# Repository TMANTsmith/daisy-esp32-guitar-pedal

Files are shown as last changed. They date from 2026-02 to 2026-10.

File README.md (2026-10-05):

# Daisy Esp32 Pedal

This is a guitar pedal with the goal of combining the audio processing power of the Daisy Seed with the wifi capabilities of the Esp32C series (currently only testing the C6). This way you can fully control the guitar pedal with your phone connected by a website hosted by the esp32 and for low-latantcy tasks physical buttons will be on the board. This will allow for greator flexability through the user being able to add or remove buttons by making changes to the website allowing them to have any configuration they want.

## What is used

### Hardware

The mini-pcb which includes TRS jacks for audio processing does not currently have the esp32 but processing audio with just the daisy seed is working

The full-pcb inclued a esp32 which is connected to the daisy seed through UART (SPI is also connected but is unused) and includes 2 TS jacks this pcb has been designed tested.

#### mini-pcb

- [x] Finished development
- [x] Passed testing

#### full-pcb

| Front | Back |
| :---: | :---: |
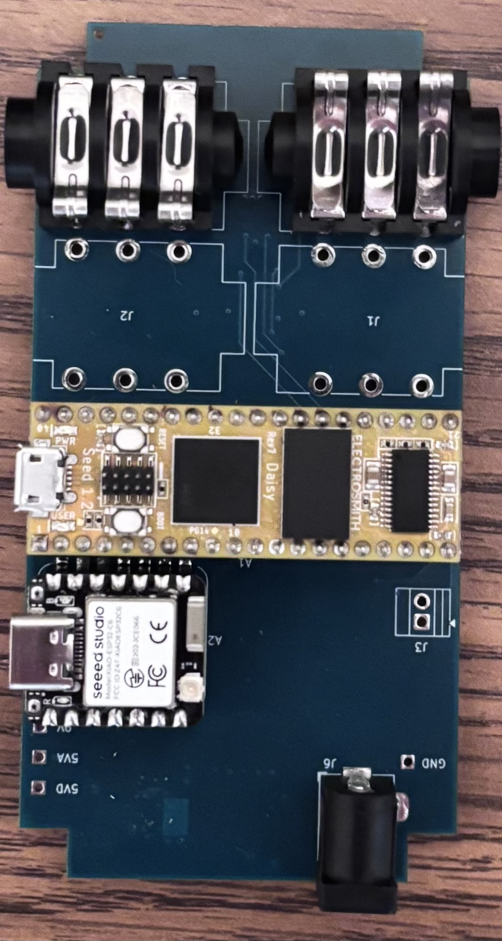
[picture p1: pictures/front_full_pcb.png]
|  |  |

- [x] Finished development
- [x] Passed testing

#### seed-pedal

This will copy the new 3Seed datasheet recommended configuration for instrument level audio and will be the final version

- [ ] Finished development
- [ ] Passed testing

### Software

The project is written in rust and uses embassy as the async exacutor. Specifily the [daisy-embassy](https://github.com/daisy-embassy/daisy-embassy/tree/master) which has some audio stuff, like a DMA buffer, built in.

## Examples

So far there is only one example which is just on main.rs which does a FFT using [microfft](https://gitlab.com/teskje/microfft-rs) but includes things like using the SDRAM on the seed as the heap, interupts and how to share information between them, how to make and use buffer for audio anaysis, and more.

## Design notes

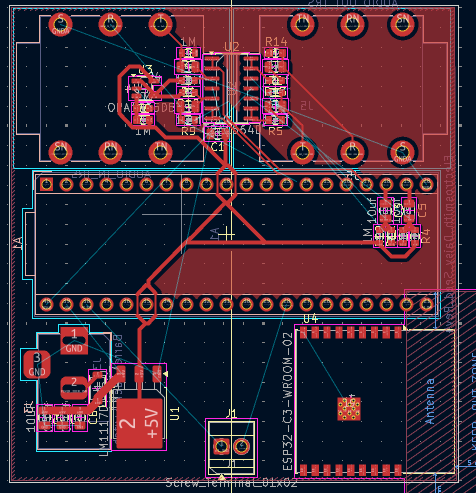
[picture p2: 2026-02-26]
seed-pedal/pcb.png

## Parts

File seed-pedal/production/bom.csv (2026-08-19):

Designator | Footprint | Quantity | Value | LCSC Part #
5VA1, 5VD1, 9V1, GND1 | PinHeader_1x01_P2.54mm_Vertical | 4 | TestPoint
A1 | Electrosmith_Daisy_Seed | 1 | Electrosmith_Daisy_Seed_Rev4 (2 1x20 pin headers required) | C50984
A2 | XIAO-ESP32-C6-DIP | 1 | XIAO-ESP32-C6-DIP (2 1x7 pin headers required) | C5371993
C1, C14, C17, C18, C19, C2 | 0805 | 6 | 0.1uf | C49678
C10, C7 | 0805 | 2 | 2.2nf | C28260
C11 | 0805 | 1 | 0.01uf | C1710
C12 | CP_EIA-3528-21_Kemet-B | 1 | 100uf | C16133
C13, C3, C4, C5, C6, C8, C9 | 0805 | 7 | 10uf | C440198
C15 | CP_EIA-7343-31_Kemet-D | 1 | 220uf | C242173
C16 | 0805 | 1 | 0.33uf | C1740
D1 | D_SMA | 1 | SS14 | C2480
D2, D3 | D_SMA | 2 | SS34 | C8678
D4 | 0805 | 1 | LED | C2297
FB1 | 0603 | 1 | 120Ω@100MHz | C14709
J6 | BarrelJack_Horizontal | 1 | Barrel_Jack_Switch | C16214
L1 | L_Changjiang_FNR8040S | 1 | 18uH | C168130
R1, R11, R8 | 0603 | 3 | 100 | C22775
R10, R14, R7 | 0603 | 3 | 3.3K | C22978
R12, R3, R4, R5, R6, R9 | 0603 | 6 | 2M | C22976
R13, R16, R2 | 0603 | 3 | 10k | C25804
R15 | 0603 | 1 | 1k | C21190
U1 | SOIC-14_3.9x8.7mm_P1.27mm | 1 | OPA1664D | C69414
U2 | TI_SO-PowerPAD-8_ThermalVias | 1 | TPS5430DDA | C9864
U3 | SOT-89-3 | 1 | 78L05G-AB3-R | C71136
U4 | SOT-23-3 | 1 | CJ431 | C3113

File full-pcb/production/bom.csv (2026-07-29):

Designator | Footprint | Quantity | Value | LCSC Part #
C1 | CP_EIA-7343-31_Kemet-D | 1 | 220uf | C242173
C11, C15, C18, C19, C3, C5, C6, C7, C9 | 0805 | 9 | 10uf | C440198
C12, C14, C16, C17 | 0805 | 4 | 0.1uf | C49678
C13, C2 | 0805 | 2 | 2.2nf | C28260
C20 | 0805 | 1 | 0.01uf | C1710
D2 | 0805 | 1 | LED | C2297
D3 | D_SMA | 1 | SS14 | C2480
D5, D6 | D_SMA | 2 | SS34 | C8678
J1, J6 | TerminalBlock_Xinya_XY308-2.54-2P_1x02_P2.54mm_Horizontal | 2 | Screw_Terminal_01x02 | C8465
J3 | BarrelJack_Horizontal | 1 | Barrel_Jack_Switch | C16214
J4, J7 | Jack_6.35mm_Neutrik_NMJ6HCD3_Horizontal | 2 | AUDIO_IN_TRS | C368502
J5, J8 | Jack_6.35mm_Neutrik_NMJ6HCD3_Horizontal | 2 | AUDIO_OUT_TRS | C368502
L1 | L_Changjiang_FNR8040S | 1 | 18uH | C168130
R1, R10, R11, R12, R5, R8 | 0603 | 6 | 2M | C22976
R2, R21, R3 | 0603 | 3 | 100 | C22775
R22, R9 | 0603 | 2 | 10k | C25804
R23, R27 | 0603 | 2 | 1k | C21190
R4, R7 | 0603 | 2 | 3.3K | C22978
R6 | 0603 | 1 | 3.24k | C166817
U1 | SOT-89-3 | 1 | 78L05G-AB3-R | C71136
U2 | SOIC-14_3.9x8.7mm_P1.27mm | 1 | OPA1664D | C69414
U3 | TI_SO-PowerPAD-8_ThermalVias | 1 | TPS5430DDA
U4 | SOT-23-3 | 1 | CJ431 | C3113

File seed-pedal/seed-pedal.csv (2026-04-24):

Reference | Qty | Value | DNP | Exclude from BOM | Exclude from Board | Footprint | Datasheet
A1 | 1 | Electrosmith_Daisy_Seed_Rev4 |  |  |  | Module:Electrosmith_Daisy_Seed | https://static1.squarespace.com/static/58d03fdc1b10e3bf442567b8/t/6227e6236f02fb68d1577146/1646781988478/Daisy_Seed_datasheet_v1.0.3.pdf
C1,C2,C3,C4,C5,C6,C9,C10,C13 | 9 | 10uf |  |  |  | Capacitor_SMD:C_0805_2012Metric | ~
C7,C8,C11,C12 | 4 | 0.1uf |  |  |  | Capacitor_SMD:C_0805_2012Metric | ~
D1 | 1 | 1N5817 |  |  |  | Diode_SMD:D_SOD-123 | http://www.vishay.com/docs/88525/1n5817.pdf
D2 | 1 | LED |  |  |  | LED_SMD:LED_0805_2012Metric | ~
J1 | 1 | Screw_Terminal_01x02 |  |  |  | TerminalBlock:TerminalBlock_Xinya_XY308-2.54-2P_1x02_P2.54mm_Horizontal | ~
J3 | 1 | Barrel_Jack_Switch |  |  |  | Connector_BarrelJack:BarrelJack_Horizontal | ~
J4 | 1 | AUDIO_IN_TRS |  |  |  | Connector_Audio:Jack_6.35mm_Neutrik_NMJ6HCD3_Horizontal
J5 | 1 | AUDIO_OUT_TRS |  |  |  | Connector_Audio:Jack_6.35mm_Neutrik_NMJ6HCD3_Horizontal
R1,R2,R3,R4,R6,R7,R9,R10,R11,R12 | 10 | 1M |  |  |  | Resistor_SMD:R_0603_1608Metric | ~
R5,R15,R17,R20,R22 | 5 | 10k |  |  |  | Resistor_SMD:R_0603_1608Metric | ~
R8,R16,R18,R19 | 4 | 39k |  |  |  | Resistor_SMD:R_0603_1608Metric | ~
R13,R14,R21,R25,R26 | 5 | 100 |  |  |  | Resistor_SMD:R_0603_1608Metric | ~
R23,R24 | 2 | 100k |  |  |  | Resistor_SMD:R_0603_1608Metric | ~
R27 | 1 | 330 |  |  |  | Resistor_SMD:R_0603_1608Metric | ~
U1 | 1 | LM1117DT-5.0 |  |  |  | Package_TO_SOT_SMD:TO-252-3_TabPin2 | http://www.ti.com/lit/ds/symlink/lm1117.pdf
U2 | 1 | OPA1664D |  |  |  | Package_SO:SOIC-14_3.9x8.7mm_P1.27mm | https://www.ti.com/lit/ds/symlink/opa1664.pdf
U3 | 1 | OPA1655DBV |  |  |  | Package_TO_SOT_SMD:SOT-23-5 | https://www.ti.com/lit/ds/symlink/opa1655.pdf

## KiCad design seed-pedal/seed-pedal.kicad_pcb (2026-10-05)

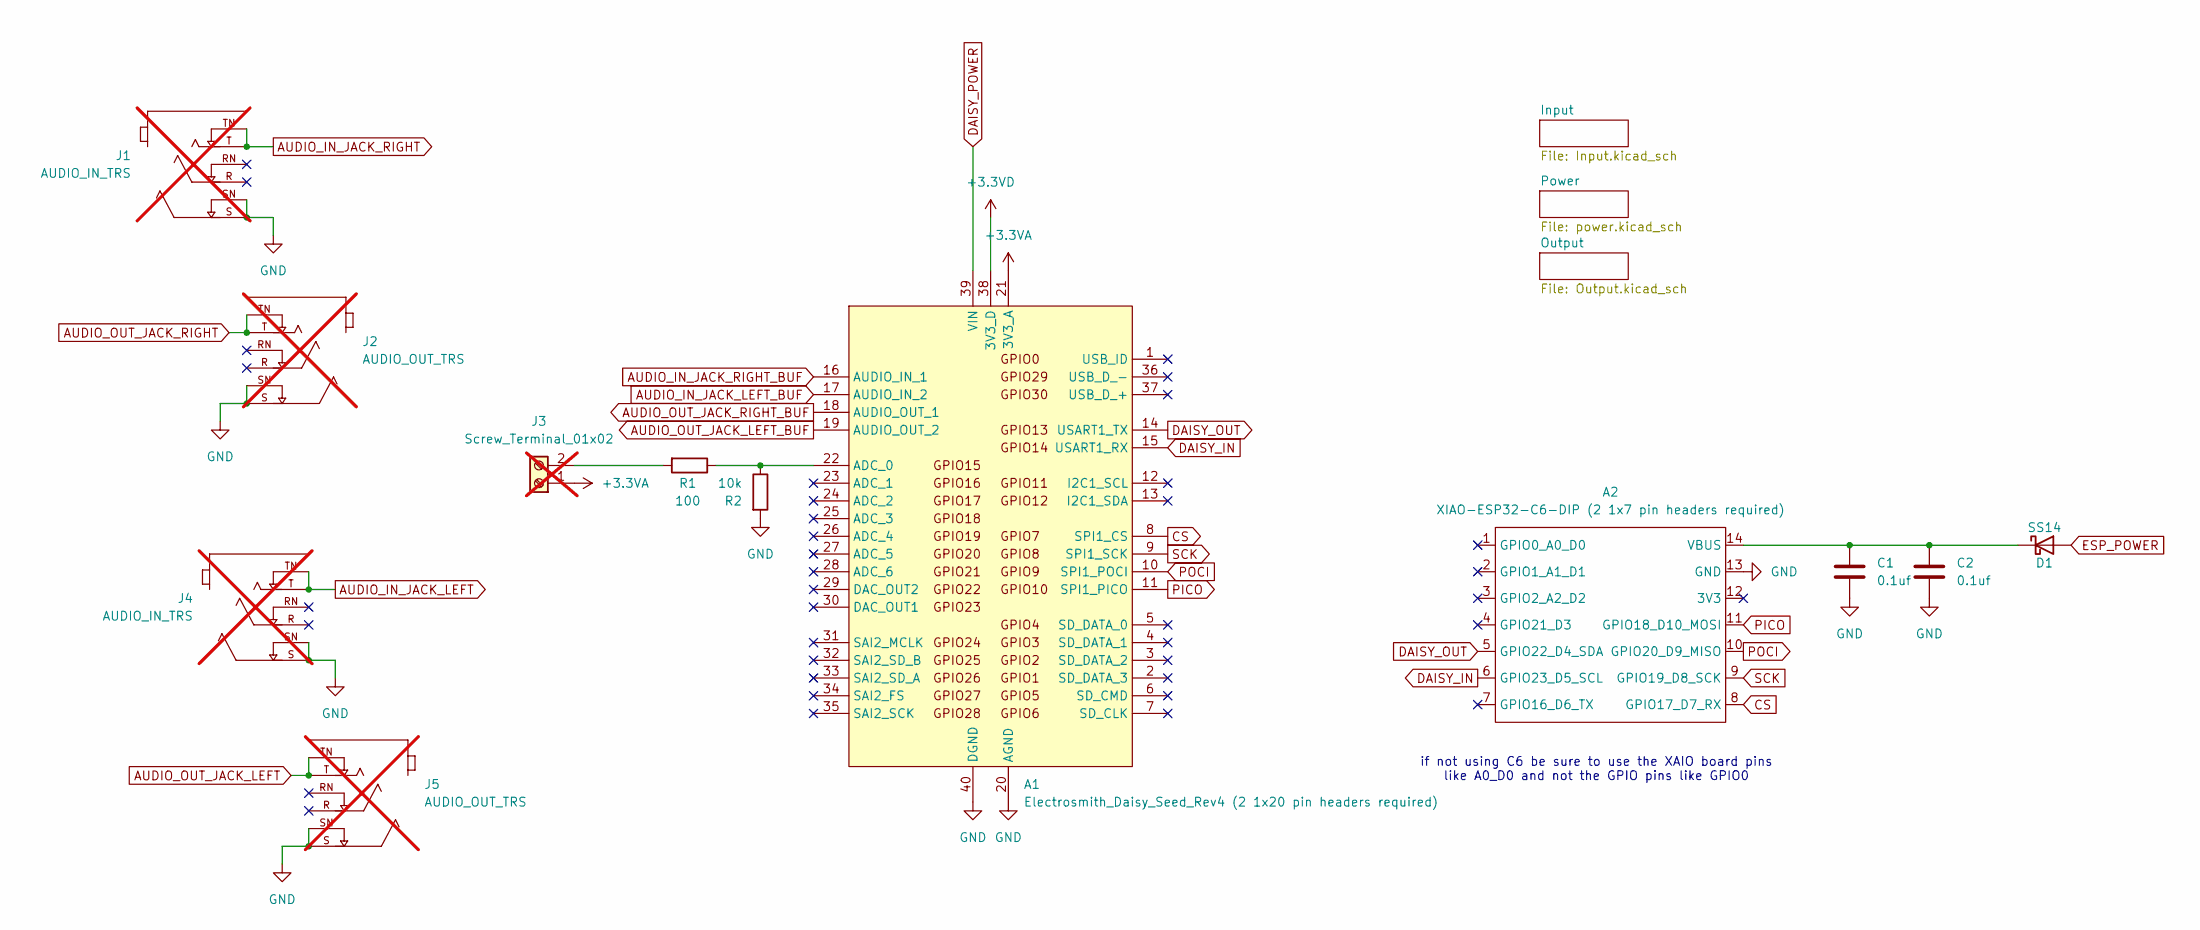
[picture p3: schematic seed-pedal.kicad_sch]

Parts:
A1: Electrosmith_Daisy_Seed_Rev4 (2 1x20 pin headers 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; Electrosmith_Daisy_Seed; MPN C50984
A2: XIAO-ESP32-C6-DIP (2 1x7 pin headers required); XIAO-ESP32-C6-DIP; MPN C5371993
C1, C2: 0.1uf; C_0603_1608Metric; MPN C49678
D1: SS14; D_SMA; MPN C2480
J1, J4: AUDIO_IN_TRS; Jack_6.35mm_Neutrik_NMJ6HCD3_Horizontal; PARTREV 26.02.2021; not fitted
J2, J5: AUDIO_OUT_TRS; Jack_6.35mm_Neutrik_NMJ6HCD3_Horizontal; PARTREV 26.02.2021; not fitted
J3: Screw_Terminal_01x02; TerminalBlock_Xinya_XY308-2.54-2P_1x02_P2.54mm_Horizontal; MPN C8465; not fitted
R1: 100; R_0603_1608Metric; MPN C22775
R2: 10k; R_0603_1608Metric; MPN C25804

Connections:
+3.3VA: A1.21 (3V3_A), J3.1
+3.3VD: A1.38 (3V3_D)
AUDIO_IN_JACK_LEFT: J4.T, J4.TN; also elsewhere on the board
AUDIO_IN_JACK_LEFT_BUF: A1.17 (AUDIO_IN_2); also elsewhere on the board
AUDIO_IN_JACK_RIGHT: J1.T, J1.TN; also elsewhere on the board
AUDIO_IN_JACK_RIGHT_BUF: A1.16 (AUDIO_IN_1); also elsewhere on the board
AUDIO_OUT_JACK_LEFT: J5.T, J5.TN; also elsewhere on the board
AUDIO_OUT_JACK_LEFT_BUF: A1.19 (AUDIO_OUT_2); also elsewhere on the board
AUDIO_OUT_JACK_RIGHT: J2.T, J2.TN; also elsewhere on the board
AUDIO_OUT_JACK_RIGHT_BUF: A1.18 (AUDIO_OUT_1); also elsewhere on the board
CS: A1.8 (SPI1_CS), A2.8 (GPIO17_D7_RX)
DAISY_IN: A1.15 (USART1_RX), A2.6 (GPIO23_D5_SCL)
DAISY_OUT: A1.14 (USART1_TX), A2.5 (GPIO22_D4_SDA)
DAISY_POWER: A1.39 (VIN); also elsewhere on the board
ESP_POWER: D1.2 (A); also elsewhere on the board
GND: A1.20 (AGND), A1.40 (DGND), A2.13 (GND), C1.2, C2.2, J1.S, J1.SN, J2.S, J2.SN, J4.S, J4.SN, J5.S, J5.SN, R2.2; also elsewhere on the board
unnamed: A1.22 (ADC_0), R1.1, R2.1
unnamed: A2.14 (VBUS), C1.1, C2.1, D1.1 (K)
unnamed: J3.2, R1.2
PICO: A1.11 (SPI1_PICO), A2.11 (GPIO18_D10_MOSI)
POCI: A1.10 (SPI1_POCI), A2.10 (GPIO20_D9_MISO)
SCK: A1.9 (SPI1_SCK), A2.9 (GPIO19_D8_SCK)

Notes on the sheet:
if not using C6 be sure to use the XAIO board pins like A0_D0 and not the GPIO pins like GPIO0

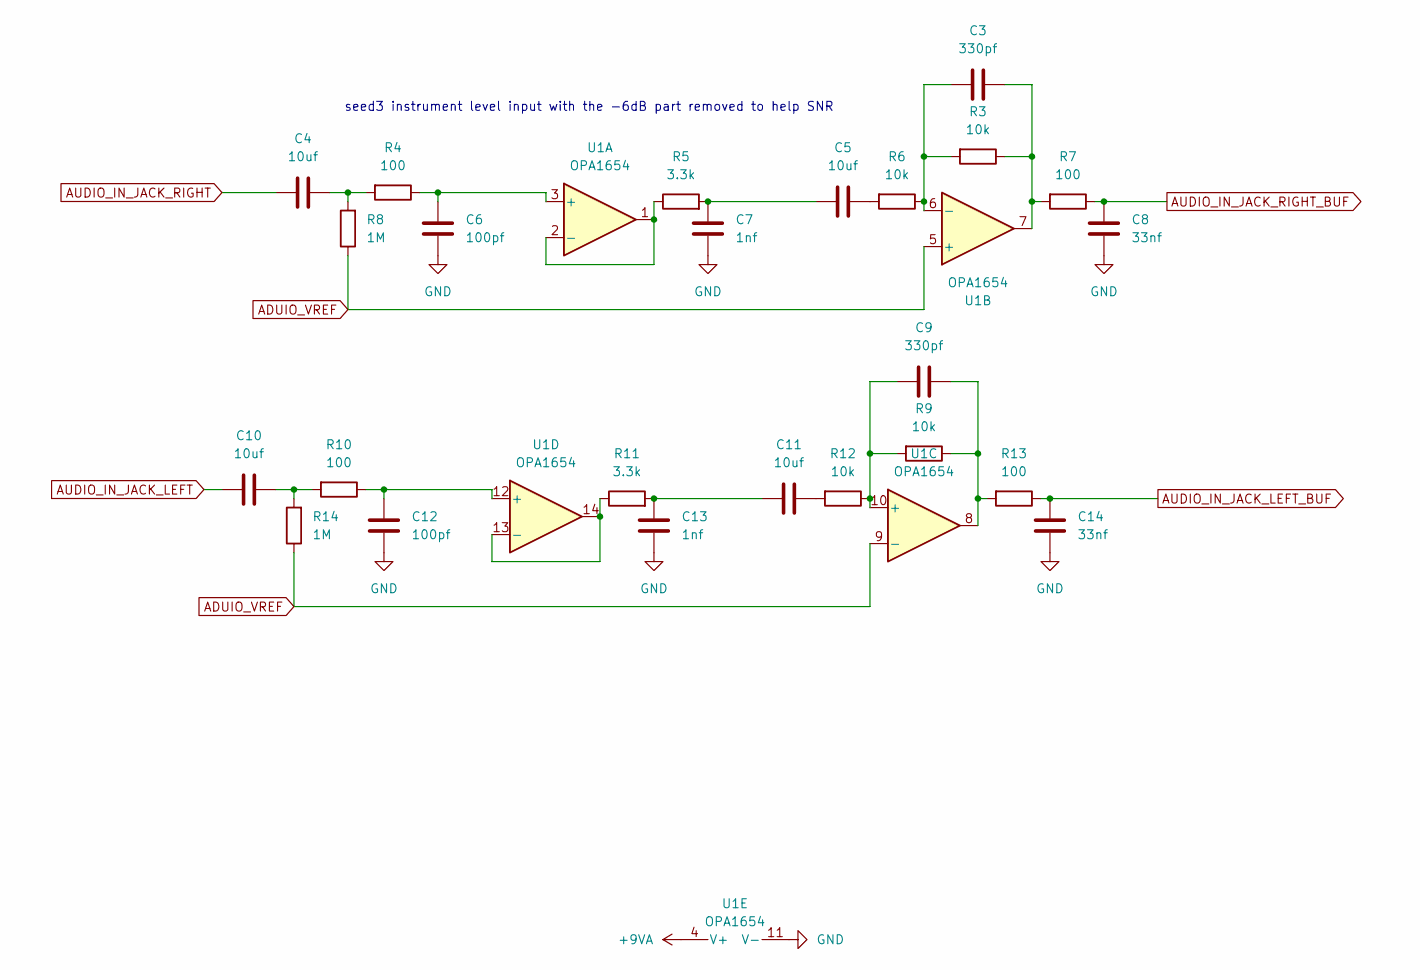
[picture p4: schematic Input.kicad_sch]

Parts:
C3, C9: 330pf; C_0603_1608Metric; MPN C1664
C4, C5, C10, C11: 10uf; C_0603_1608Metric; MPN C96446
C6, C12: 100pf; C_0603_1608Metric; MPN C14858
C7, C13: 1nf; C_0603_1608Metric; MPN C1588
C8, C14: 33nf; C_0603_1608Metric; MPN C21117
R3, R6, R9, R12: 10k; R_0603_1608Metric; MPN C25804
R4, R7, R10, R13: 100; R_0603_1608Metric; MPN C22775
R5, R11: 3.3k; R_0603_1608Metric; MPN C22978
R8, R14: 1M; R_0603_1608Metric; MPN C22935
U1: OPA1654; SOIC-14_3.9x8.7mm_P1.27mm; MPN C30026

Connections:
+9VA: U1.4 (V+); also elsewhere on the board
ADUIO_VREF: R8.1, R14.1, U1.5 (+), U1.9 (-); also elsewhere on the board
AUDIO_IN_JACK_LEFT: C10.1; also elsewhere on the board
AUDIO_IN_JACK_LEFT_BUF: C14.1, R13.1; also elsewhere on the board
AUDIO_IN_JACK_RIGHT: C4.1; also elsewhere on the board
AUDIO_IN_JACK_RIGHT_BUF: C8.1, R7.1; also elsewhere on the board
GND: C6.2, C7.2, C8.2, C12.2, C13.2, C14.2, U1.11 (V-); also elsewhere on the board
unnamed: C3.2, R3.1, R7.2, U1.7
unnamed: C4.2, R4.2, R8.2
unnamed: C5.1, C7.1, R5.2
unnamed: C5.2, R6.2
unnamed: C9.2, R9.1, R13.2, U1.8
unnamed: C10.2, R10.2, R14.2
unnamed: C11.1, C13.1, R11.2
unnamed: C11.2, R12.2
unnamed: C6.1, R4.1, U1.3 (+)
unnamed: R5.1, U1.1, U1.2 (-)
unnamed: C3.1, R3.2, R6.1, U1.6 (-)
unnamed: C9.1, R9.2, R12.1, U1.10 (+)
unnamed: C12.1, R10.1, U1.12 (+)
unnamed: R11.1, U1.13 (-), U1.14

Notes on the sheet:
seed3 instrument level input with the -6dB part removed to help SNR

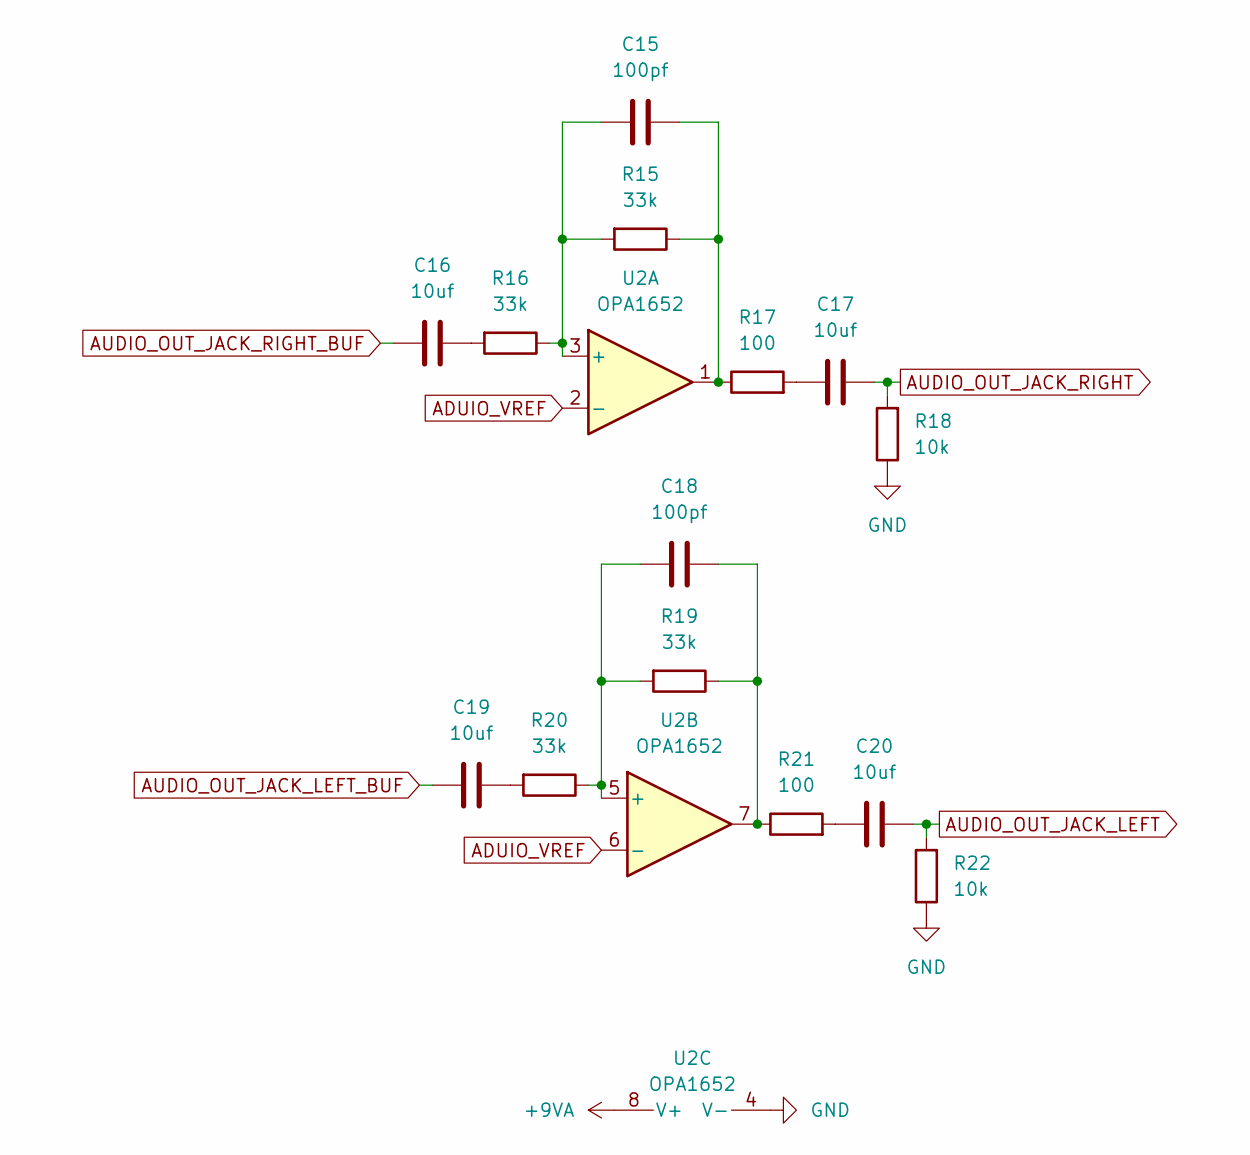
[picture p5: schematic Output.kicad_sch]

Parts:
C15, C18: 100pf; C_0603_1608Metric; MPN C14858
C16, C17, C19, C20: 10uf; C_0603_1608Metric; MPN C96446
R15, R16, R19, R20: 33k; R_0603_1608Metric; MPN C4216
R17, R21: 100; R_0603_1608Metric; MPN C22775
R18, R22: 10k; R_0603_1608Metric; MPN C25804
U2: OPA1652; SOIC-8_3.9x4.9mm_P1.27mm

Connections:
+9VA: U2.8 (V+); also elsewhere on the board
ADUIO_VREF: U2.2 (-), U2.6 (-); also elsewhere on the board
AUDIO_OUT_JACK_LEFT: C20.2, R22.2; also elsewhere on the board
AUDIO_OUT_JACK_LEFT_BUF: C19.1; also elsewhere on the board
AUDIO_OUT_JACK_RIGHT: C17.2, R18.2; also elsewhere on the board
AUDIO_OUT_JACK_RIGHT_BUF: C16.1; also elsewhere on the board
GND: R18.1, R22.1, U2.4 (V-); also elsewhere on the board
unnamed: C15.2, R15.1, R17.1, U2.1
unnamed: C16.2, R16.2
unnamed: C17.1, R17.2
unnamed: C18.2, R19.1, R21.1, U2.7
unnamed: C19.2, R20.2
unnamed: C20.1, R21.2
unnamed: C15.1, R15.2, R16.1, U2.3 (+)
unnamed: C18.1, R19.2, R20.1, U2.5 (+)

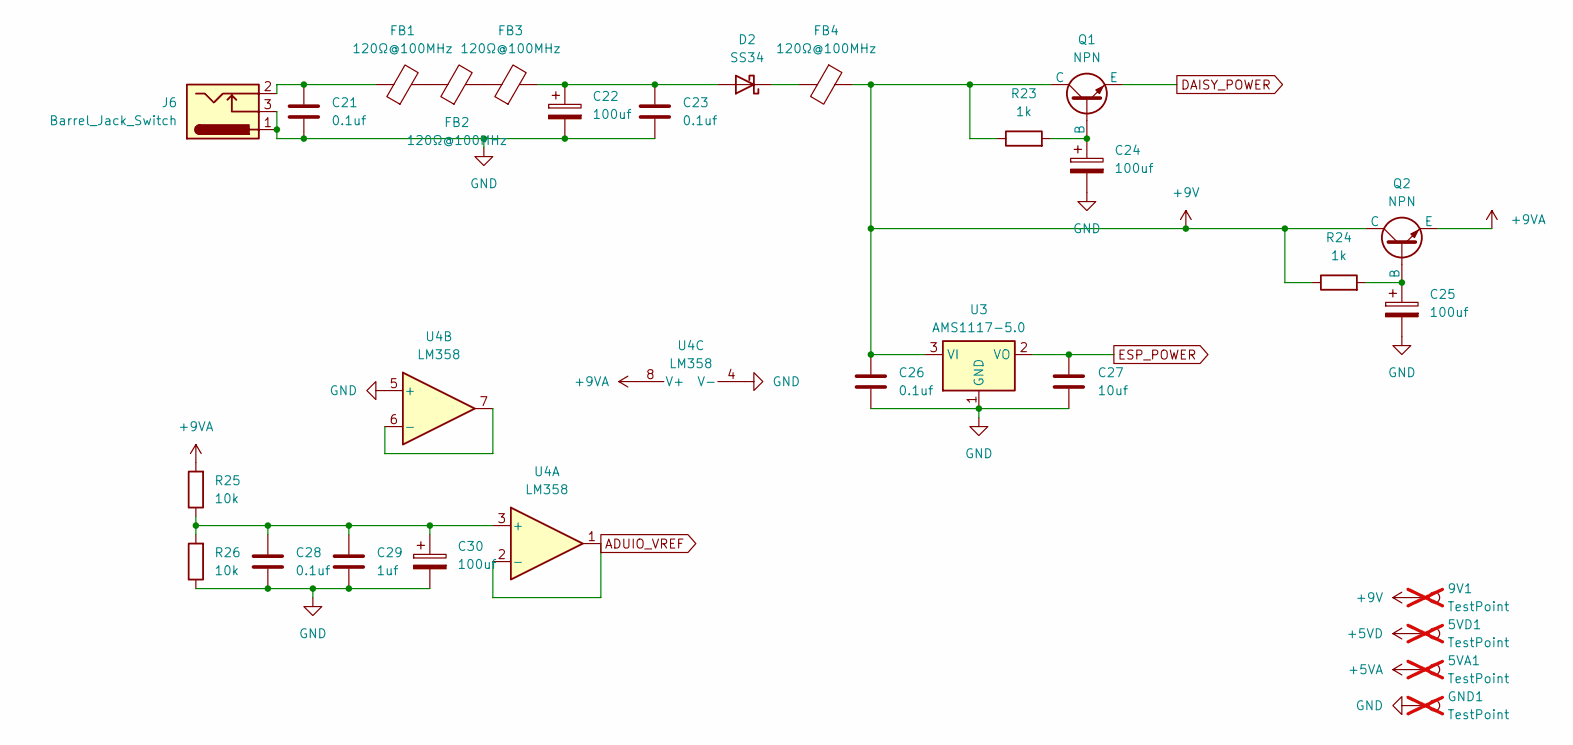
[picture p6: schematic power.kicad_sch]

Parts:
5VA1, 5VD1, 9V1: TestPoint; PinHeader_1x01_P2.54mm_Vertical; not fitted
C21, C23, C26, C28: 0.1uf; C_0805_2012Metric; MPN C49678
C22, C24, C25, C30: 100uf; CP_Radial_D8.0mm_P3.50mm; MPN C5113358
C27: 10uf; C_0805_2012Metric; MPN C15850
C29: 1uf; C_0805_2012Metric; MPN C28323
D2: SS34; D_SMA
FB1, FB2, FB3, FB4: 120Ω@100MHz; R_0603_1608Metric; MPN BLM18PG121SN1D
GND1: TestPoint; PinHeader_1x01_P2.54mm_Vertical; not fitted
J6: Barrel_Jack_Switch; BarrelJack_Horizontal; MPN C16214
Q1, Q2: NPN; SOT-89-3; MPN C41375136
R23, R24: 1k; R_0603_1608Metric; MPN C21190
R25, R26: 10k; R_0603_1608Metric; MPN C25804
U3: AMS1117-5.0; SOT-223-3_TabPin2
U4: LM358; SOIC-8_3.9x4.9mm_P1.27mm

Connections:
+9V: 9V1.1, C26.1, FB4.1, Q1.1 (C), Q2.1 (C), R23.1, R24.1, U3.3 (VI)
+9VA: Q2.3 (E), R25.2, U4.8 (V+); also elsewhere on the board
ADUIO_VREF: U4.1, U4.2 (-); also elsewhere on the board
DAISY_POWER: Q1.3 (E); also elsewhere on the board
ESP_POWER: C27.2, U3.2 (VO); also elsewhere on the board
GND: C21.2, C22.2, C23.2, C24.2, C25.2, C26.2, C27.1, C28.2, C29.2, C30.2, GND1.1 (1_1), J6.1, J6.3, R26.1, U3.1 (GND), U4.4 (V-), U4.5 (+); also elsewhere on the board
unnamed: C21.1, FB1.1, J6.2
unnamed: C22.1, C23.1, D2.2 (A), FB3.2
unnamed: D2.1 (K), FB4.2
unnamed: FB1.2, FB2.1
unnamed: FB2.2, FB3.1
unnamed: C24.1, Q1.2 (B), R23.2
unnamed: C25.1, Q2.2 (B), R24.2
unnamed: C28.1, C29.1, C30.1, R25.1, R26.2, U4.3 (+)
unnamed: U4.6 (-), U4.7

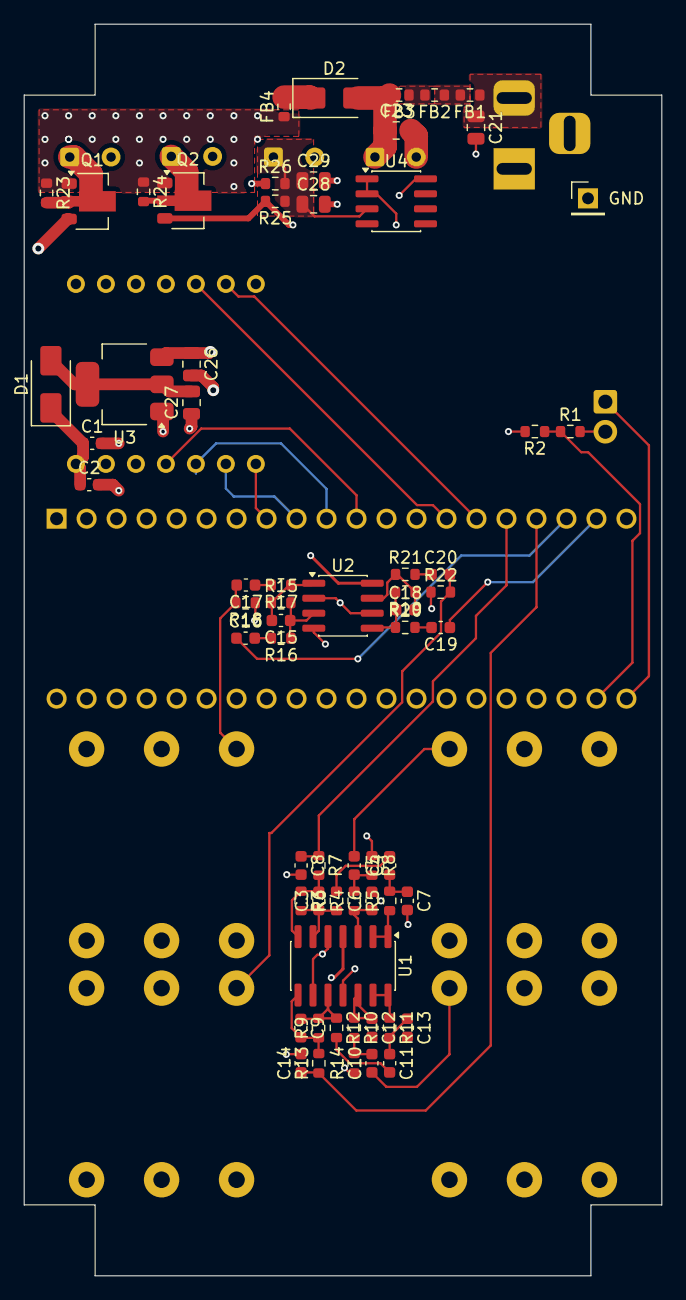
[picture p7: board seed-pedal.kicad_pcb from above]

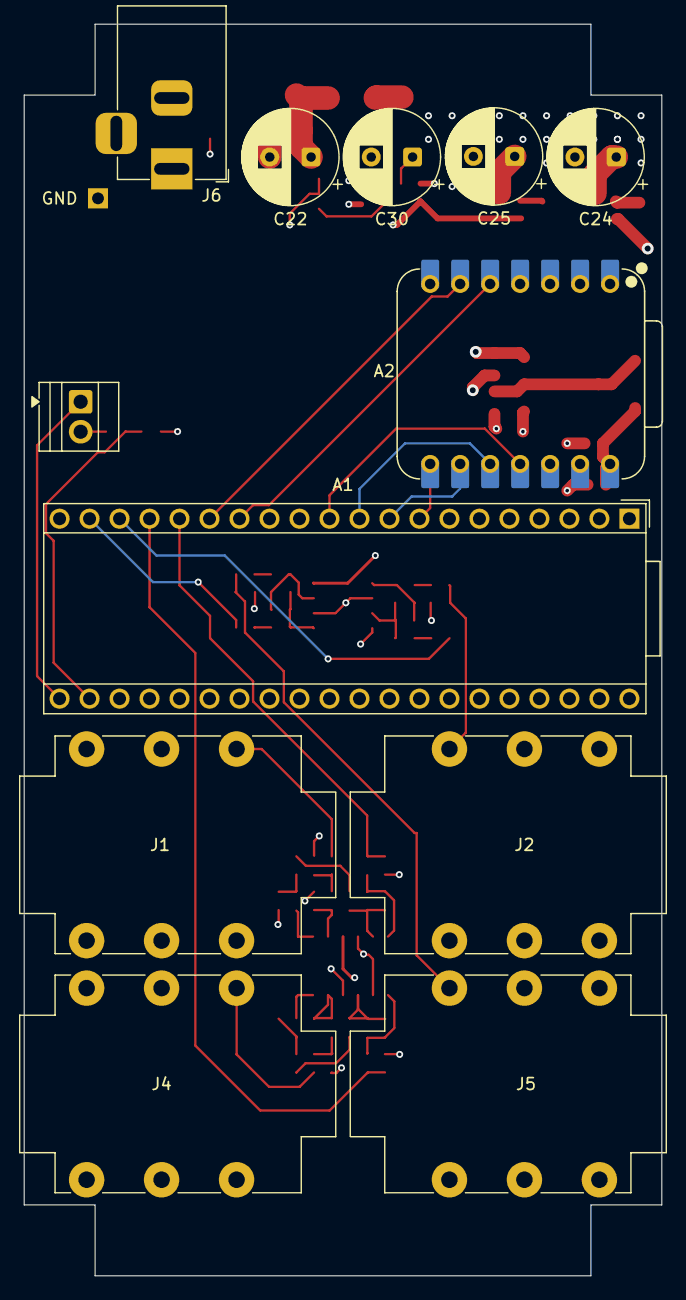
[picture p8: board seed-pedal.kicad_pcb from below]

Board: 4 copper layers, 54.0 x 106.0 mm, 77 parts (12 on the bottom side), 55 nets.

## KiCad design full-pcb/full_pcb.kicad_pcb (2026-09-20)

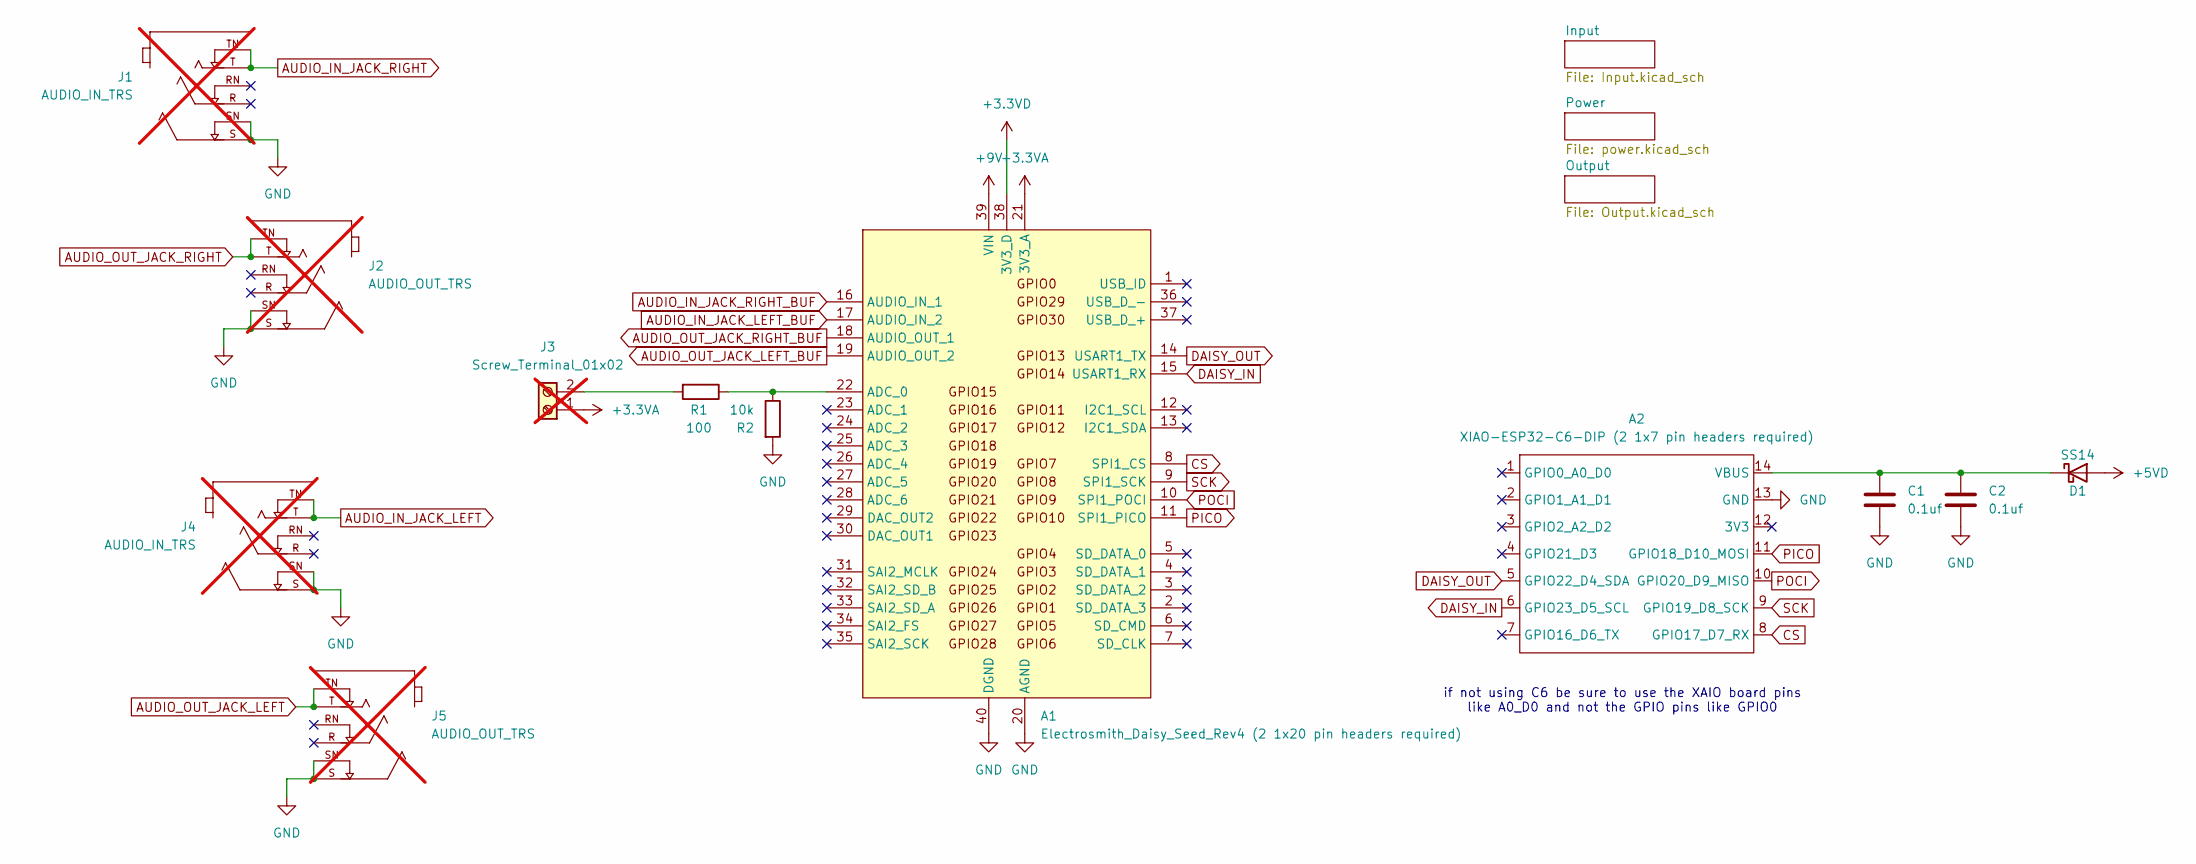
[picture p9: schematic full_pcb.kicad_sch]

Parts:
A1: Electrosmith_Daisy_Seed_Rev4 (2 1x20 pin headers 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; Electrosmith_Daisy_Seed; MPN C50984
A2: XIAO-ESP32-C6-DIP (2 1x7 pin headers required); XIAO-ESP32-C6-DIP; MPN C5371993
C1, C2: 0.1uf; C_0805_2012Metric; MPN C49678
D1: SS14; D_SMA; MPN C2480
J1, J4: AUDIO_IN_TRS; Jack_6.35mm_Neutrik_NMJ6HCD3_Horizontal; PARTREV 26.02.2021; not fitted
J2, J5: AUDIO_OUT_TRS; Jack_6.35mm_Neutrik_NMJ6HCD3_Horizontal; PARTREV 26.02.2021; not fitted
J3: Screw_Terminal_01x02; TerminalBlock_Xinya_XY308-2.54-2P_1x02_P2.54mm_Horizontal; MPN C8465; not fitted
R1: 100; R_0603_1608Metric; MPN C22775
R2: 10k; R_0603_1608Metric; MPN C25804

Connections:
+3.3VA: A1.21 (3V3_A), J3.1
+3.3VD: A1.38 (3V3_D)
+5VD: D1.2 (A); also elsewhere on the board
+9V: A1.39 (VIN); also elsewhere on the board
AUDIO_IN_JACK_LEFT: J4.T, J4.TN; also elsewhere on the board
AUDIO_IN_JACK_LEFT_BUF: A1.17 (AUDIO_IN_2); also elsewhere on the board
AUDIO_IN_JACK_RIGHT: J1.T, J1.TN; also elsewhere on the board
AUDIO_IN_JACK_RIGHT_BUF: A1.16 (AUDIO_IN_1); also elsewhere on the board
AUDIO_OUT_JACK_LEFT: J5.T, J5.TN; also elsewhere on the board
AUDIO_OUT_JACK_LEFT_BUF: A1.19 (AUDIO_OUT_2); also elsewhere on the board
AUDIO_OUT_JACK_RIGHT: J2.T, J2.TN; also elsewhere on the board
AUDIO_OUT_JACK_RIGHT_BUF: A1.18 (AUDIO_OUT_1); also elsewhere on the board
CS: A1.8 (SPI1_CS), A2.8 (GPIO17_D7_RX)
DAISY_IN: A1.15 (USART1_RX), A2.6 (GPIO23_D5_SCL)
DAISY_OUT: A1.14 (USART1_TX), A2.5 (GPIO22_D4_SDA)
GND: A1.20 (AGND), A1.40 (DGND), A2.13 (GND), C1.2, C2.2, J1.S, J1.SN, J2.S, J2.SN, J4.S, J4.SN, J5.S, J5.SN, R2.2; also elsewhere on the board
unnamed: A1.22 (ADC_0), R1.1, R2.1
unnamed: A2.14 (VBUS), C1.1, C2.1, D1.1 (K)
unnamed: J3.2, R1.2
PICO: A1.11 (SPI1_PICO), A2.11 (GPIO18_D10_MOSI)
POCI: A1.10 (SPI1_POCI), A2.10 (GPIO20_D9_MISO)
SCK: A1.9 (SPI1_SCK), A2.9 (GPIO19_D8_SCK)

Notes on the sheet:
if not using C6 be sure to use the XAIO board pins like A0_D0 and not the GPIO pins like GPIO0

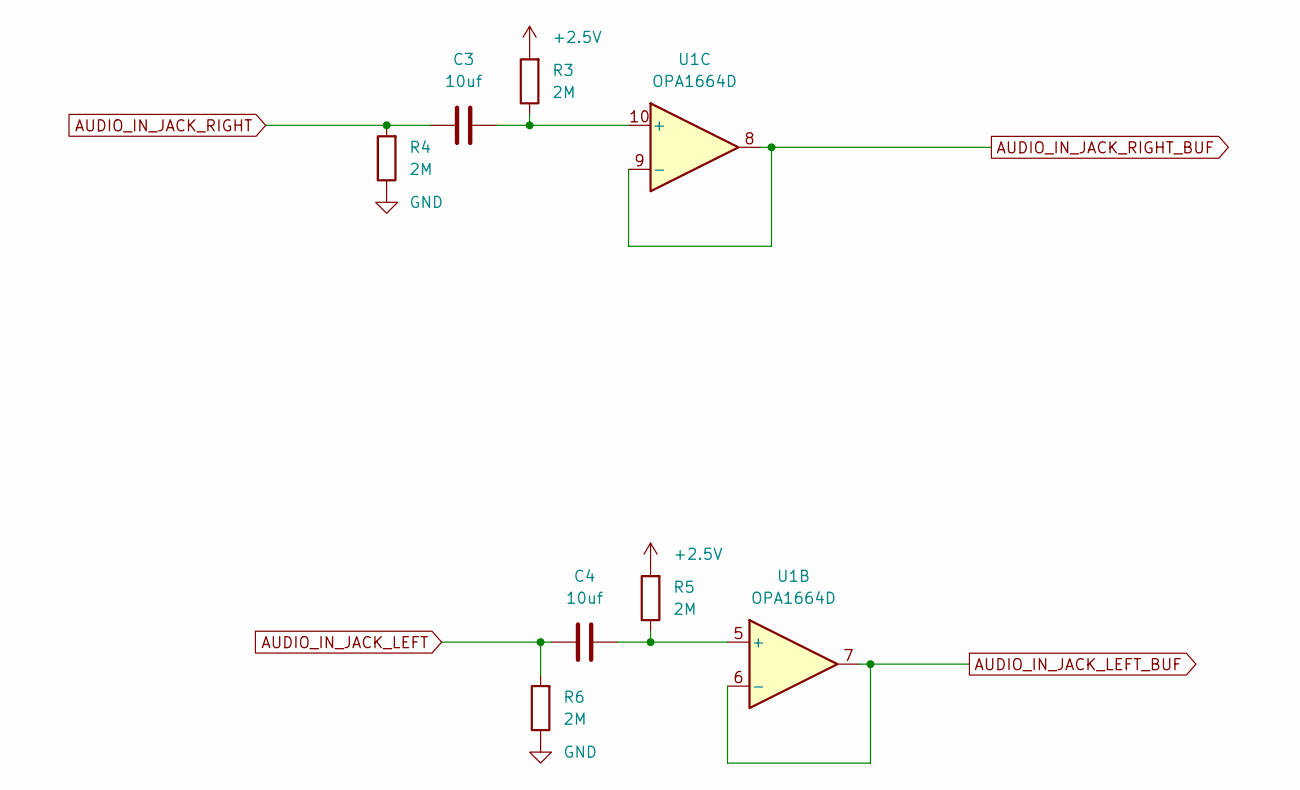
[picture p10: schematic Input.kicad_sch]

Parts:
C3, C4: 10uf; C_0805_2012Metric; MPN C440198
R3, R4, R5, R6: 2M; R_0603_1608Metric; MPN C22976
U1: OPA1664D; SOIC-14_3.9x8.7mm_P1.27mm; MPN C69414

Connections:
+2.5V: R3.2, R5.2; also elsewhere on the board
AUDIO_IN_JACK_LEFT: C4.1, R6.2; also elsewhere on the board
AUDIO_IN_JACK_LEFT_BUF: U1.6 (-), U1.7; also elsewhere on the board
AUDIO_IN_JACK_RIGHT: C3.1, R4.2; also elsewhere on the board
AUDIO_IN_JACK_RIGHT_BUF: U1.8, U1.9 (-); also elsewhere on the board
GND: R4.1, R6.1; also elsewhere on the board
unnamed: C4.2, R5.1, U1.5 (+)
unnamed: C3.2, R3.1, U1.10 (+)

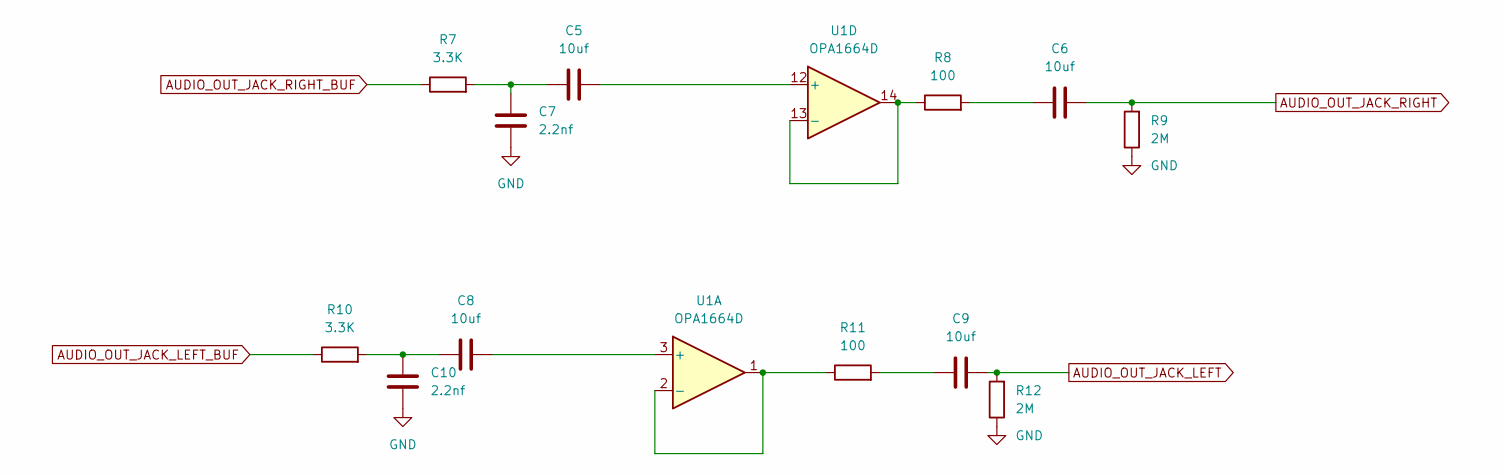
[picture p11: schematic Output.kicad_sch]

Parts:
C5, C6, C8, C9: 10uf; C_0805_2012Metric; MPN C440198
C7, C10: 2.2nf; C_0805_2012Metric; MPN C28260
R7, R10: 3.3K; R_0603_1608Metric; MPN C22978
R8, R11: 100; R_0603_1608Metric; MPN C22775
R9, R12: 2M; R_0603_1608Metric; MPN C22976
U1: OPA1664D; SOIC-14_3.9x8.7mm_P1.27mm; MPN C69414

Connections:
AUDIO_OUT_JACK_LEFT: C9.2, R12.2; also elsewhere on the board
AUDIO_OUT_JACK_LEFT_BUF: R10.1; also elsewhere on the board
AUDIO_OUT_JACK_RIGHT: C6.2, R9.2; also elsewhere on the board
AUDIO_OUT_JACK_RIGHT_BUF: R7.1; also elsewhere on the board
GND: C7.1, C10.1, R9.1, R12.1; also elsewhere on the board
unnamed: C5.1, C7.2, R7.2
unnamed: C6.1, R8.2
unnamed: C9.1, R11.2
unnamed: C8.1, C10.2, R10.2
unnamed: C8.2, U1.3 (+)
unnamed: R11.1, U1.1, U1.2 (-)
unnamed: C5.2, U1.12 (+)
unnamed: R8.1, U1.13 (-), U1.14

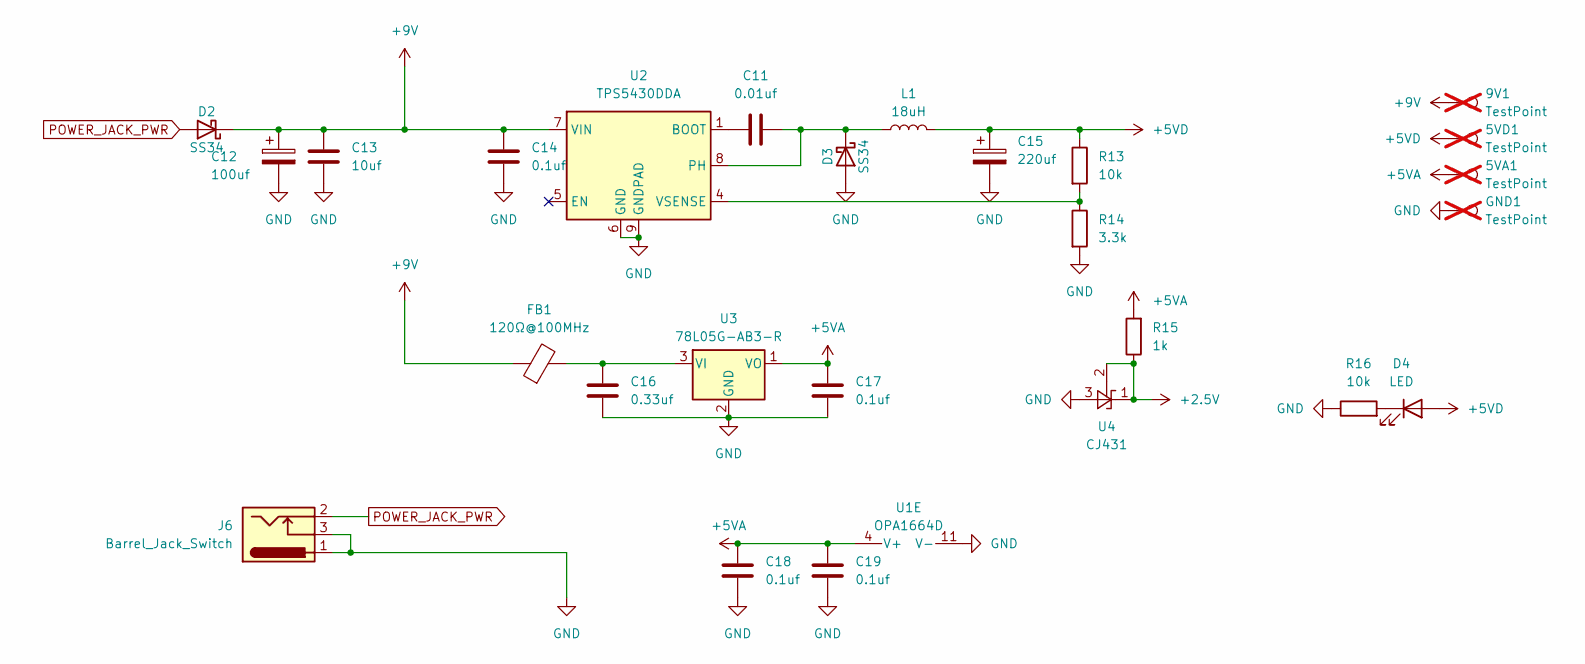
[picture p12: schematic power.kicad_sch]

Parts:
5VA1, 5VD1, 9V1: TestPoint; PinHeader_1x01_P2.54mm_Vertical; not fitted
C11: 0.01uf; C_0805_2012Metric; MPN C1710
C12: 100uf; CP_EIA-3528-21_Kemet-B; MPN C16133
C13: 10uf; C_0805_2012Metric; MPN C440198
C14, C17, C18, C19: 0.1uf; C_0805_2012Metric; MPN C49678
C15: 220uf; CP_EIA-7343-31_Kemet-D; MPN C242173
C16: 0.33uf; C_0805_2012Metric; MPN C1740
D2, D3: SS34; D_SMA; MPN C8678
D4: LED; LED_0805_2012Metric; MPN C2297
FB1: 120Ω@100MHz; R_0603_1608Metric; MPN C14709
GND1: TestPoint; PinHeader_1x01_P2.54mm_Vertical; not fitted
J6: Barrel_Jack_Switch; BarrelJack_Horizontal; MPN C16214
L1: 18uH; L_Changjiang_FNR8040S; MPN C168130
R13, R16: 10k; R_0603_1608Metric; MPN C25804
R14: 3.3k; R_0603_1608Metric; MPN C22978
R15: 1k; R_0603_1608Metric; MPN C21190
U1: OPA1664D; SOIC-14_3.9x8.7mm_P1.27mm; MPN C69414
U2: TPS5430DDA; TI_SO-PowerPAD-8_ThermalVias; MPN C9864
U3: 78L05G-AB3-R; SOT-89-3; MPN C71136
U4: CJ431; SOT-23-3; MPN C3113

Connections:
+2.5V: R15.1, U4.1 (FB), U4.2 (K); also elsewhere on the board
+5VA: 5VA1.1 (1_1), C17.2, C18.1, C19.1, R15.2, U1.4 (V+), U3.1 (VO)
+5VD: 5VD1.1 (1_1), C15.1, D4.2 (A), L1.2, R13.1; also elsewhere on the board
+9V: 9V1.1 (1_1), C12.1, C13.2, C14.2, D2.1 (K), FB1.1, U2.7 (VIN); also elsewhere on the board
GND: C12.2, C13.1, C14.1, C15.2, C16.1, C17.1, C18.2, C19.2, D3.2 (A), GND1.1 (1_1), J6.1, J6.3, R14.2, R16.1, U1.11 (V-), U2.6 (GND), U2.9 (GNDPAD), U3.2 (GND), U4.3 (A); also elsewhere on the board
unnamed: C11.2, D3.1 (K), L1.1, U2.8 (PH)
unnamed: D4.1 (K), R16.2
unnamed: C11.1, U2.1 (BOOT)
unnamed: R13.2, R14.1, U2.4 (VSENSE)
unnamed: C16.2, FB1.2, U3.3 (VI)
POWER_JACK_PWR: D2.2 (A), J6.2

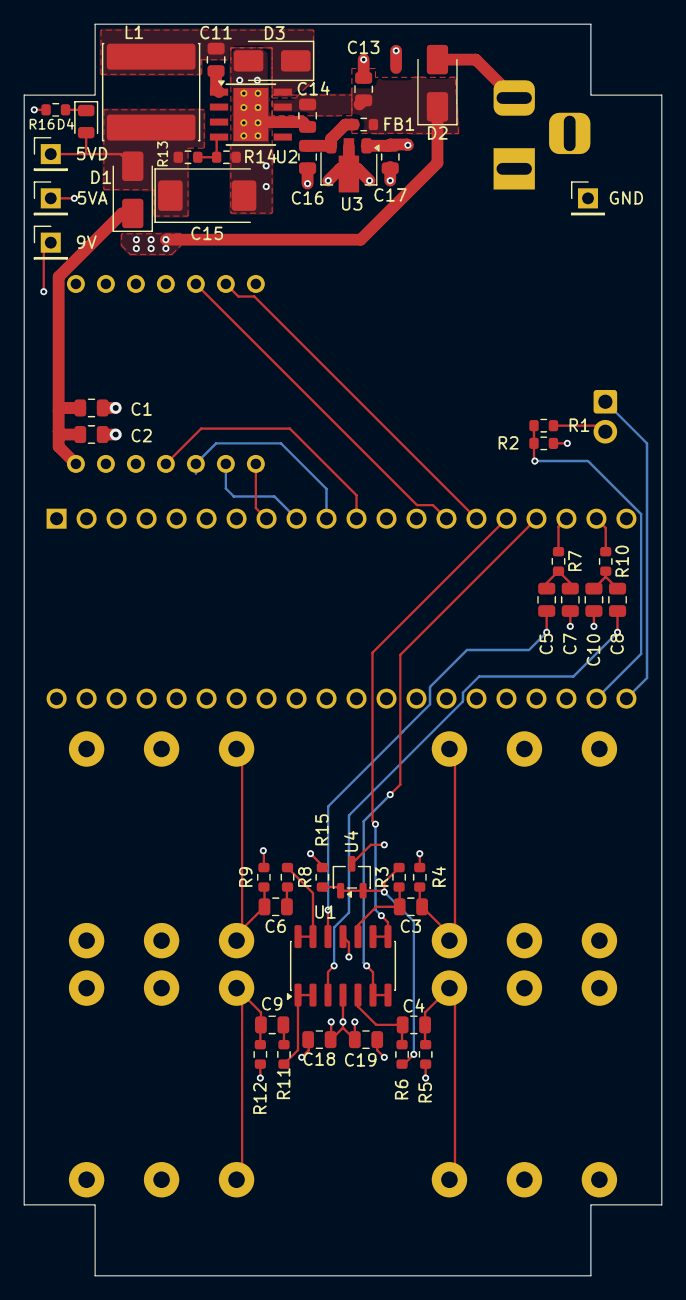
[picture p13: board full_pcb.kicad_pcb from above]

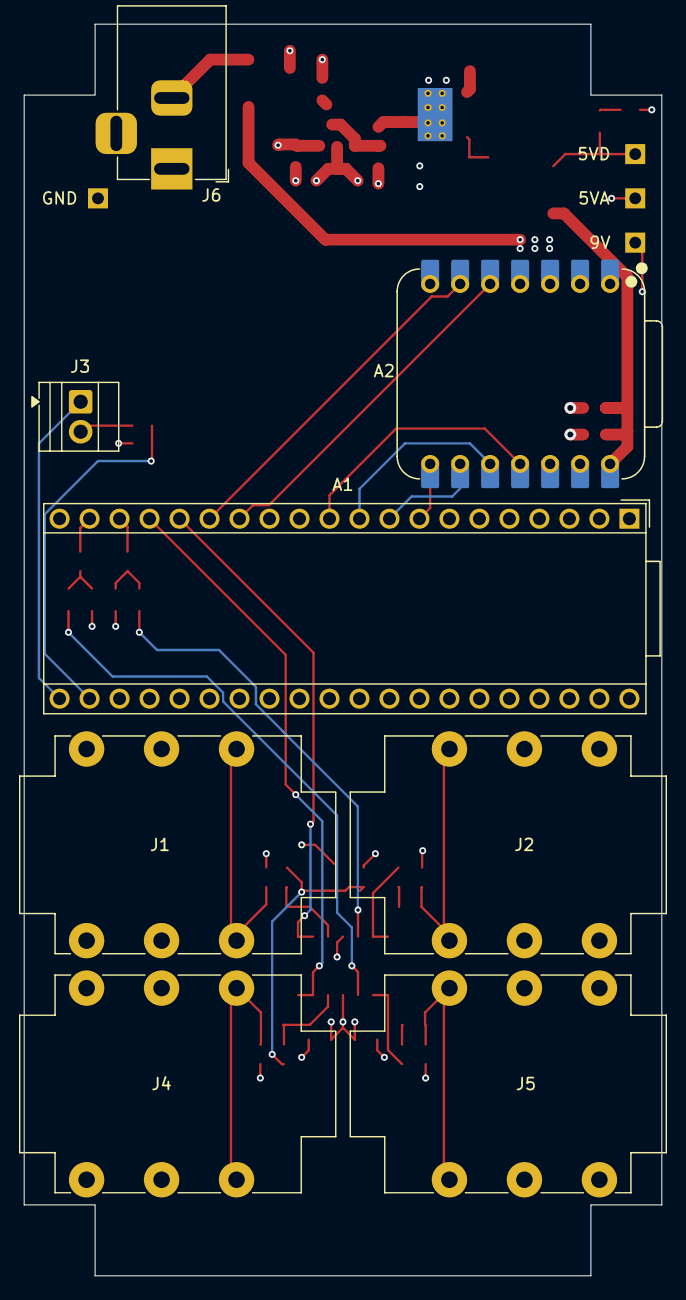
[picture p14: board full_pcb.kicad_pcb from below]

Board: 4 copper layers, 54.0 x 106.0 mm, 56 parts (8 on the bottom side), 39 nets.

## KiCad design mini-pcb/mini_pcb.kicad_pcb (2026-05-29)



Board: 4 copper layers, 58.5 x 60.5 mm, 50 parts (9 on the bottom side), 35 nets.

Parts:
5V1, 9V1: TestPoint; TestPoint_Pad_D2.0mm
A1: Electrosmith_Daisy_Seed_Rev4; Electrosmith_Daisy_Seed
AUDIO_IN1: TestPoint; TestPoint_Pad_D2.0mm
AUDIO_RAW1: TestPoint; TestPoint_Pad_D2.0mm
C1, C4: 10uf; CP_EIA-3216-18_Kemet-A
C2, C13, C16, C17: 1nf; C_0805_2012Metric
C3, C5, C6, C7, C9, C11: 10uf; C_0805_2012Metric
C8, C10, C12: 0.1uf; C_0805_2012Metric
D1: 1N5817; D_SOD-123
D2: LED; LED_0805_2012Metric
GND1, GND2: TestPoint; TestPoint_Pad_D2.0mm
J1, J6: Screw_Terminal_01x02; TerminalBlock_Xinya_XY308-2.54-2P_1x02_P2.54mm_Horizontal
J3: Barrel_Jack_Switch; BarrelJack_Horizontal
J4: AUDIO_IN_TRS; Jack_6.35mm_Neutrik_NMJ6HCD3_Horizontal
J5: AUDIO_OUT_TRS; Jack_6.35mm_Neutrik_NMJ6HCD3_Horizontal
R1, R5, R8, R10: 2M; R_0603_1608Metric
R2, R9: 7.5k; R_0603_1608Metric
R3, R4, R6, R7, R13, R14, R21, R25, R26: 100; R_0603_1608Metric
R22: 10k; R_0603_1608Metric
R23: 1k; R_0603_1608Metric
R27: 330; R_0603_1608Metric
U2: OPA1664D; SOIC-14_3.9x8.7mm_P1.27mm
U3: LM1117DT-5.0; TO-252-2
U4: CJ431; SOT-23-3

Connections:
+2.5V: R1.2, R5.2, R23.1, U4.1 (FB), U4.2 (K)
+3.3VD: A1.38 (3V3_D), J1.1
+5V: 5V1.1 (1_1), C4.1, C10.1, C12.1, D2.2 (A), R23.2, U2.4 (V+), U3.2 (VO)
+9V: 9V1.1 (1_1), A1.39 (VIN), C1.1, C8.1, D1.1 (K), U3.3 (VI)
AUDIO_IN_JACK_LEFT: AUDIO_RAW1.1 (1_1), J4.T, R3.2
AUDIO_IN_JACK_LEFT_BUF: A1.17 (AUDIO_IN_2), R13.2
AUDIO_IN_JACK_RIGHT: J4.R, R4.2
AUDIO_IN_JACK_RIGHT_BUF: A1.16 (AUDIO_IN_1), AUDIO_IN1.1 (1_1), R14.2
AUDIO_OUT_JACK_LEFT: J5.T, R26.2
AUDIO_OUT_JACK_LEFT_BUF: A1.19 (AUDIO_OUT_2), R6.1
AUDIO_OUT_JACK_RIGHT: J5.R, R25.2
AUDIO_OUT_JACK_RIGHT_BUF: A1.18 (AUDIO_OUT_1), R7.1
GND: A1.20 (AGND), A1.40 (DGND), C1.2, C2.1, C4.2, C8.2, C10.2, C12.2, C13.1, C16.1, C17.1, GND1.1 (1_1), GND2.1 (1_1), J3.1, J3.3, J4.S, J5.S, R8.1, R10.1, R22.2, R27.1, U2.11 (V-), U3.1 (GND), U4.3 (A)
unnamed: A1.28 (ADC_6), R21.2, R22.1
unnamed: A1.12 (I2C1_SCL), J6.1
unnamed: A1.13 (I2C1_SDA), J6.2
unnamed: C3.1, R7.2
unnamed: C5.1, R6.2
unnamed: C6.2, R26.1
unnamed: C7.1, R3.1, R10.2
unnamed: C9.2, R25.1
unnamed: C11.1, R4.1, R8.2
unnamed: C6.1, C16.2, R2.2
unnamed: C9.1, C17.2, R9.2
unnamed: D2.1 (K), R27.2
unnamed: J1.2, R21.1
unnamed: C7.2, R1.1, U2.3 (+)
unnamed: C2.2, R13.1, U2.1, U2.2 (-)
unnamed: C11.2, R5.1, U2.5 (+)
unnamed: C13.2, R14.1, U2.6 (-), U2.7
unnamed: C5.2, U2.10 (+)
unnamed: R2.1, U2.8, U2.9 (-)
unnamed: C3.2, U2.12 (+)
unnamed: R9.1, U2.13 (-), U2.14
POWER_JACK_PWR: D1.2 (A), J3.2

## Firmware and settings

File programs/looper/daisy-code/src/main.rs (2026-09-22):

#![no_std]
#![no_main]
extern crate alloc;



mod modules;

use modules::looper::*;
use alloc::boxed::Box;
use core::num::Wrapping;
use daisy_embassy::{
    audio::{Interface, Running},
    hal::{
        self, bind_interrupts, dma,
        mode::Async,
        peripherals,
        usart::{self, Config as UsartConfig, Uart, UartRx, UartTx},
    },
    new_daisy_board,
    sdram::SDRAM_SIZE,
    DaisyBoard,
};
use defmt::{debug, info, unwrap};
use defmt_rtt as _;
use embassy_executor::{InterruptExecutor, Spawner};
use embassy_sync::{blocking_mutex::raw::CriticalSectionRawMutex, signal::Signal};
use embassy_time::Delay;
use embedded_alloc::LlffHeap as Heap;
use hal::interrupt::{self, InterruptExt, Priority};
use panic_probe as _;
use pcobs::{deserialize, serialize};
use settings::*;
use static_cell::StaticCell;

bind_interrupts!(struct Irqs {
    USART1 => usart::InterruptHandler<peripherals::USART1>;
    DMA1_STREAM3 => dma::InterruptHandler<peripherals::DMA1_CH3>;
    DMA1_STREAM4 => dma::InterruptHandler<peripherals::DMA1_CH4>;
});



static COMMAND: Signal<CriticalSectionRawMutex, CommandUart> = Signal::new();
static BUFA: Signal<CriticalSectionRawMutex, Box<[f32; FFT_INPUT]>> = Signal::new();
static BUFB: Signal<CriticalSectionRawMutex, Box<[f32; FFT_INPUT]>> = Signal::new();
static BUFC: Signal<CriticalSectionRawMutex, Box<[f32; FFT_INPUT]>> = Signal::new();

// audio_task -> BUFB -> compute -> BUFC -> SPI -> BUFA -> audio_task

static BUFFER_FILLER: StaticCell<BufferFiller<FFT_INPUT>> = StaticCell::new();

static EXECUTOR_HIGH: InterruptExecutor = InterruptExecutor::new();
static EXECUTOR_LOW: InterruptExecutor = InterruptExecutor::new();



#[global_allocator]
static HEAP: Heap = Heap::empty();

#[hal::interrupt]
unsafe fn TIM15() {
    unsafe { EXECUTOR_HIGH.on_interrupt() }
}
#[hal::interrupt]
unsafe fn TIM17() {
    unsafe { EXECUTOR_LOW.on_interrupt() }
}


#[defmt::panic_handler]
fn panic() -> ! {
    core::panic!("panic via defmt::panic!")
}

#[embassy_executor::task]
async fn uart_receiver(mut uart: UartRx<'static, Async>) {
    let mut buf = Box::new([0; 64]);
    let mut counter = 0usize;
    loop {
        let n = match uart.read_until_idle(&mut buf[counter..]).await {
            Err(e) => { info!("uart read error: {}", e); continue; }
            Ok(n) => n,
        };

        let end = counter + n; 
        let mut start = 0;

        while let Some(rel_pos) = buf[start..end].iter().position(|&b| b == FRAME_DELIM) {
            let delim = start + rel_pos;
            let frame = &mut buf[start..delim]; 

            match deserialize::<CommandUart>(frame, frame.len()) {
                Ok(command) => {
                    COMMAND.signal(command);
                }
                Err(e) => info!("bad cobs frame {}", defmt::Debug2Format(&e)),
            }

            start = delim + 1;
        }

        if start == end {
            // consumed everything, reset to front of buffer
            counter = 0;
        } else if start > 0 {
            // shift leftover partial frame to the front of buf
            buf.copy_within(start..end, 0);
            counter = end - start;
        } else {
            // no delimiter found at all — still mid-frame, keep accumulating
            counter = end;
            if counter == buf.len() {
                info!("frame too large, dropping");
                counter = 0;
            }
        }
    }
}



#[embassy_executor::task]
async fn uart_sender(mut uart: UartTx<'static, Async>){
    // WAIT C 
    // SIGNAL A 

    // try to remove box here and optimize for more memory


    let mut cobs = Box::new([0_u8; COBS_BUF]);
    let mut convertion: [BinValue; FFT_BINS] = [BinValue::from(0u8); FFT_BINS];

    loop {
        let mut bufc = BUFC.wait().await;
        let buffer: &mut [f32; FFT_BINS] = (&mut bufc[..FFT_BINS]).try_into().unwrap();
        FromF32::slice_from_f32(buffer, &mut convertion);
        let msg = FFTUart::new(convertion);
        let len = serialize(&msg, cobs.as_mut_slice());
        BUFA.signal(bufc);

        match len {
            Err(err) =>
            {
                info!("uart error {}", defmt::Debug2Format(&err));
            },
            Ok(len) =>
            {
                cobs[len] = FRAME_DELIM;
                uart.write(&cobs[..=len]).await.unwrap();
            }
        }
    }
}
#[embassy_executor::task]
async fn fft_compute() {

    let mut mags = [0.0f32; FFT_BINS]; // reusable scratch, stack-allocated, outside the loop

    loop {
        let mut buffer = BUFB.wait().await;
        let result = compute::<FFT_INPUT, FFT_BINS>(&mut buffer);
        result[0].im = 0.0;

        for i in 0..FFT_BINS{
            mags[i] = libm::sqrtf(result[i].norm_sqr());
        }

        buffer[..FFT_BINS].copy_from_slice(&mags);

        BUFC.signal(buffer);
    }
}


#[embassy_executor::task]
async fn audio_task(
    mut interface: Interface<'static, Running>,
    buffer_filler: &'static mut BufferFiller<FFT_INPUT>,
) {
    // WAIT A 
    // SIGNAL B
    //debug!("entered audio");
    use Mute::Mute;
    use self::Mute::Unmute;
    let mut command: CommandUart = CommandUart::Mute(Unmute);
    unwrap!(
        interface
            .start_callback(move |input, output| {
                let mut frames: FrameBlock = [(0.0, 0.0); 32];
                convert_to(input, &mut frames);

                if let Some(c) = COMMAND.try_take() {
                    command = c;
                }

                for frame in frames.iter_mut() {
                    match buffer_filler.add(frame.1) {
                        Err(BufState::Ready(e)) => {  /* debug!("buffer sent to compute:"); */ BUFB.signal(e); },
                        Err(BufState::NoBuf) => { 
                            if let Some(b) = BUFA.try_take() { 
                                buffer_filler.set_buf(b); 
                                //debug!("buffer receaved from compute");
                            } 
                        },

                        _ => ()
                    }
                }

                if command == CommandUart::Mute(Mute) {
                    frames.fill((0.0, 0.0));
                }
                convert_from(&frames, output);

            })
            .await
    );
}

#[embassy_executor::main]
async fn main(_spawner: Spawner) {
    debug!("====program start====");

    let config = daisy_embassy::default_rcc();
    let p = hal::init(config);
    let board: DaisyBoard<'_> = new_daisy_board!(p);



    let mut core = cortex_m::Peripherals::take().unwrap();
    let mut sdram = board.sdram.build(&mut core.MPU, &mut core.SCB);


    let mut delay = Delay;

    let ram_ptr: *mut u32 =  sdram.init(&mut delay) as *mut _;





    // Initialize the global allocator over the SDRAM region, BEFORE any
    // alloc-based type (Vec, Box, HeapRb, etc.) is constructed.
    unsafe {
        HEAP.init(ram_ptr as usize, SDRAM_SIZE);
    }



    let pins = board.pins;

    let mut config = UsartConfig::default();
    config.baudrate = BAUDRATE;
    let uart = Uart::new(p.USART1, pins.d14, pins.d13, p.DMA1_CH3, p.DMA1_CH4, Irqs, config).unwrap();
    let (uart_tx, uart_rx) = uart.split(); 

    let interface = board
        .audio_peripherals
        .prepare_interface(Default::default())
        .await;


    let interface = unwrap!(interface.start_interface().await);

    interrupt::TIM15.set_priority(Priority::P3);
    interrupt::TIM17.set_priority(Priority::P5);
    let spawner_high = EXECUTOR_HIGH.start(interrupt::TIM15); // reader
    let spawner_low = EXECUTOR_LOW.start(interrupt::TIM17); // computer

    let buffer_filler = BUFFER_FILLER.init(BufferFiller::<FFT_INPUT>::new());



    spawner_high.spawn(audio_task(interface, buffer_filler).unwrap());
    spawner_low.spawn(fft_compute().unwrap());
    spawner_low.spawn(uart_sender(uart_tx).unwrap());
    spawner_low.spawn(uart_receiver(uart_rx).unwrap());

    let buf_a = Box::new([0_f32; FFT_INPUT]);
    let buf_b = Box::new([0_f32; FFT_INPUT]);
    let buf_c = Box::new([0_f32; FFT_INPUT]);

    BUFA.signal(buf_a);
    BUFB.signal(buf_b);
    BUFC.signal(buf_c);

    debug!("spawned tasks");
}

pub type Frame = (f32, f32);
pub type FrameBlock = [Frame; 32];

#[inline(always)]
pub fn convert_to(input: &[u32], output: &mut [Frame]) {
    for (chunk, frame) in input.chunks(2).zip(output.iter_mut()) {
        frame.0 = to_f32(chunk[0]);
        frame.1 = to_f32(chunk[1]);
    }
}

#[inline(always)]
pub fn convert_from(input: &[Frame], output: &mut [u32]) {
    for (frame, chunk) in input.iter().zip(output.chunks_mut(2)) {
        chunk[0] = to_u32(frame.0);
        chunk[1] = to_u32(frame.1);
    }
}

#[inline(always)]
fn to_f32(y: u32) -> f32 {
    let y = (Wrapping(y) + Wrapping(0x0080_0000)).0 & 0x00FF_FFFF; // convert to i32
    (y as f32 / 8_388_608.0) - 1.0 // (2^24) / 2
}

#[inline(always)]
fn to_u32(x: f32) -> u32 {
    let x = x * 8_388_607.0;
    let x = x.clamp(-8_388_608.0, 8_388_607.0);
    (x as i32) as u32
}

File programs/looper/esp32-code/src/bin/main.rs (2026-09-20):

#![no_std]
#![no_main]


extern crate alloc;

const CONSTS_JS: &str = concat!(
    "HTTP/1.0 200 OK\r\nContent-Type: application/javascript\r\n\r\n",
    include_str!("../consts.js")
);

use pcobs::{serialize, deserialize};
use settings::*;
use alloc::boxed::Box;
use core::error::Error;
use core::marker::PhantomData;
use core::{net::Ipv4Addr, str::FromStr};
use defmt::info;
use embassy_time::Instant;
use embassy_sync::channel::Channel;
use embassy_sync::signal::Signal;
use embassy_sync::blocking_mutex::raw::{CriticalSectionRawMutex, NoopRawMutex};
use embedded_websocket::{
    WebSocketServer, WebSocketReceiveMessageType, WebSocketSendMessageType,
};
use embassy_executor::Spawner;
use embassy_futures::select::{select, Either};
use embassy_net::{
    IpListenEndpoint,
    Ipv4Cidr,
    Runner,
    Stack,
    StackResources,
    StaticConfigV4,
    tcp::TcpSocket,
};
use embassy_time::{Duration, Timer};
use embedded_io_async::Write;
use esp_alloc as _;
use esp_backtrace as _;
use esp_hal::{
    clock::CpuClock,
    interrupt::software::SoftwareInterruptControl,
    ram,
    rng::Rng,
    timer::timg::TimerGroup,
    Blocking,
    Async,
    uart::{Uart, RxConfig, TxConfig, uhci, uhci::Uhci, uhci::UhciRx, uhci::UhciTx, uhci::UhciDmaRxTransfer, uhci::UhciDmaTxTransfer},
    dma::{DmaRxBuf, DmaTxBuf},
    dma_buffers
};
use esp_hal::uart::Config as UartConfig;
use esp_println::{print, println};
use esp_radio::wifi::{Config, ControllerConfig, Interface, WifiController, ap::AccessPointConfig};
esp_bootloader_esp_idf::esp_app_desc!();

macro_rules! mk_static {
    ($t:ty,$val:expr) => {{
        static STATIC_CELL: static_cell::StaticCell<$t> = static_cell::StaticCell::new();
        #[deny(unused_attributes)]
        let x = STATIC_CELL.uninit().write(($val));
        x
    }};
}

const GW_IP_ADDR_ENV: Option<&'static str> = option_env!("GATEWAY_IP");

// ---------------------------------------------------------------------------
// Spectrum config — keep these in sync with the constants at the top of the
// <script> block in index.html and the consts in daisy.
// ---------------------------------------------------------------------------
/// Number of bins in the spectrum. Must be a power of two. Increasing this
/// increases RAM use (FFT_BINS* 4 bytes for the shared buffer, plus
/// roughly the same again for the outgoing frame buffer) and network load.
/// Sample rate of the audio the spectrum was computed from. Only used here
/// for the startup log message; the actual bin->frequency mapping happens in
/// the browser.
/// How often a new spectrum frame is pushed to a connected WebSocket client.
const SPECTRUM_PUSH_INTERVAL: Duration = Duration::from_millis(50); // ~20 fps

const SPECTRUM_PAYLOAD_BYTES: usize = FFT_BINS* core::mem::size_of::<BinValue>(); // f32 = 4 bytes each
const WS_FRAME_MARGIN: usize = 16; // header + margin for the binary WS frame
const TCP_BUF_SIZE: usize = SPECTRUM_PAYLOAD_BYTES + 512;

const HTML_PAGE: &str = concat!("HTTP/1.0 200 OK\r\n\r\n", include_str!("../index.html"));


const NYQUIST_HZ: usize = SAMPLE_RATE / 2;          // 24_000
const AUDIBLE_CUTOFF_HZ: usize = 20_000;
// round UP so we never clip a bin that's still under the cutoff
    const TX_BINS: usize =
((AUDIBLE_CUTOFF_HZ as usize * FFT_BINS) + NYQUIST_HZ as usize - 1)
    / NYQUIST_HZ as usize;                        // 1707 bins @ FFT_BINS=2048
    const TX_PAYLOAD_BYTES: usize = TX_BINS * core::mem::size_of::<BinValue>();

// ---------------------------------------------------------------------------
// Shared spectrum state.
//
// Whatever produces your FFT data (a mic + FFT task, I2S DMA callback, etc.)
// should call `set_spectrum(&data)` whenever a new frame is ready. The WS
// task below just reads whatever is currently here on its own timer — it
// doesn't care how often set_spectrum is called.
// +2 is for crc16
// ---------------------------------------------------------------------------

/// FROM UART TO WEB
static SPECTRUM_A: Signal<CriticalSectionRawMutex, [BinValue; FFT_BINS]> = Signal::new();
static COMMAND: Signal<CriticalSectionRawMutex, CommandUart> = Signal::new();
/// FROM WEB TO UART


/// Publish a new spectrum frame. `data[i]` should be the magnitude (in dB,
/// e.g. -100.0 to 0.0) of frequency bin `i`, where bin `i` corresponds to
/// `i * (SAMPLE_RATE / 2) / FFT_BINS` Hz. If your FFT output is
/// linear magnitude rather than dB, either convert it before calling this
/// (`20.0 * libm::log10f(mag.max(1e-6))`), or send it as-is and set
/// `INPUT_IS_DB = false` in index.html's <script>.


#[esp_rtos::main]
async fn main(spawner: Spawner) -> ! {
    let config = esp_hal::Config::default().with_cpu_clock(CpuClock::max());
    let peripherals = esp_hal::init(config);
    esp_alloc::heap_allocator!(#[ram(reclaimed)] size: 64 * 1024);
    esp_alloc::heap_allocator!(size: 36 * 1024);
    let timg0 = TimerGroup::new(peripherals.TIMG0);
    let sw_int = SoftwareInterruptControl::new(peripherals.SW_INTERRUPT);
    esp_rtos::start(timg0.timer0, sw_int.software_interrupt0);



    let rx = peripherals.GPIO22;
    let tx = peripherals.GPIO23;

    let uart_config = UartConfig::default()
        .with_baudrate(BAUDRATE)
        .with_rx(RxConfig::default().with_fifo_full_threshold(64)); 

    let mut uart = Uart::new(peripherals.UART0, uart_config).unwrap()
        .with_rx(rx)
        .with_tx(tx);

    const MIN: usize = if (SPECTRUM_PAYLOAD_BYTES + 512) < 4095 { SPECTRUM_PAYLOAD_BYTES + 512  } else { 4095 };
    // use these tx buffers
    let (rx_buffer_a, rx_descriptors_a, tx_buffer_a, tx_descriptors_a) = dma_buffers!(MIN);
    let (rx_buffer_b, rx_descriptors_b, tx_buffer_b, tx_descriptors_b) = dma_buffers!(MIN);

    let dma_rx_a = DmaRxBuf::new(rx_descriptors_a, rx_buffer_a).unwrap();
    let dma_rx_b = DmaRxBuf::new(rx_descriptors_b, rx_buffer_b).unwrap();

    // these tx buffers may be too big 
    let dma_tx_a = DmaTxBuf::new(tx_descriptors_a, tx_buffer_a).unwrap();
    let dma_tx_b = DmaTxBuf::new(tx_descriptors_b, tx_buffer_b).unwrap();

    let mut uhci = Uhci::new(uart, peripherals.UHCI0, peripherals.DMA_CH0).into_async();
    uhci.apply_rx_config(
        &uhci::RxConfig::default().with_chunk_limit(dma_rx_a.len().min(4095) as u16),
    )
        .unwrap();
    uhci.apply_tx_config(&uhci::TxConfig::default())
        .unwrap();
    uhci.set_uart_config(&uart_config).unwrap();

    let (mut uhci_rx, mut uhci_tx) = uhci.split();

    let mut uart_dma_rx = UartDmaRead::new();
    let mut uart_dma_tx = UartDmaRead::new();


    let access_point_config =
        Config::AccessPoint(AccessPointConfig::default().with_ssid("esp-radio"));
    println!("Starting wifi");
    let (controller, interfaces) = esp_radio::wifi::new(
        peripherals.WIFI,
        ControllerConfig::default().with_initial_config(access_point_config),
    )
    .unwrap();
    println!("Wifi started!");
    let device = interfaces.access_point;
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

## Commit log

2025-09-23 Initial commit: project structure
    [esp32-fx_v2.kicad_pcb, esp32-fx_v2.kicad_sch]
2025-09-25 added images of pcb
    [esp32-fx_v2.kicad_pcb]
2025-09-27 im tired of trying to make something i will not use
2025-10-07 add latest PCB backup
2025-10-09 Track freeverb as normal directory
2025-10-14 fixed input and output values and removed opamp
    [main.rs]
2025-10-14 added mute layout
    [esp32-fx_v2.kicad_pcb, esp32-fx_v2.kicad_sch]
2025-10-14 added back opamp
    [esp32-fx_v2.kicad_pcb, esp32-fx_v2.kicad_sch]
2025-10-14 made opamps neater
    [esp32-fx_v2.kicad_pcb]
2025-10-14 REALLY cleaned up opamps
    [esp32-fx_v2.kicad_pcb]
2025-10-15 editded pcb
    [esp32-fx_v2.kicad_pcb]
2025-10-17 creadted esp32 workspace
2025-10-19 disabled std lib and rewrote drivers
2025-10-20 rewrote I2C driver
2025-11-07 big changes esp32 -> raspberry pi zero 2 W
    [esp32-fx.kicad_pcb, esp32-fx.kicad_sch, esp32-fx_v2.kicad_pcb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]
2025-11-09 wrote I2C I2S and using multible cores
    [esp32-fx.kicad_pcb, esp32-fx.kicad_sch]
2025-11-24 esp32+daisy seed code
2025-11-27 finaly got the adc part to compile
2025-11-30 added RTIC for UART and audio still neet to do somthing for pots and mabey screen
2025-12-03 fixed compiler errors and started on UART error handling
    [main.rs]
2025-12-04 changed enum command to a list and changed errors in UART
2025-12-05 added error handling for UART works in lib not in main
2025-12-06 added good error handing and logging
    [main.rs]
2025-12-06 almost fixed compiler errors
    [main.rs]
2025-12-06 added uart write checking
2025-12-07 made error handling even better
    [main.rs]
2025-12-07 finilized error and loging i think
    [main.rs]
2025-12-12 added error handling and adcs errors
    [main.rs]
2025-12-15 started fixing the UART struct with verification
    [main.rs]
2025-12-16 made uart errors better
    [main.rs]
2025-12-16 made struct so that it return UartString
2025-12-18 made uart redo when block
2026-01-01 cleaned up files
    [esp32-fx.kicad_pcb, esp32-fx.kicad_sch]
2026-01-01 got the adc to write to dma mabey
2026-01-02 adc and uart look good need to fix compile errors
    [main.rs]
2026-01-03 almost no compile errors need to fix rx_buf
    [main.rs]
2026-01-31 ADC reader working
2026-02-13 commiting pcb
    [mini_pcb.kicad_pcb, mini_pcb.kicad_sch]
2026-02-20 fixed timer issue
2026-02-22 mini-pcb layout
    [mini_pcb.kicad_pcb, mini_pcb.kicad_sch]
2026-02-22 eletronic simulation made
    [mini_pcb.kicad_pcb, mini_pcb.kicad_sch]
2026-02-26 pcb update
    [Input.kicad_sch, Output.kicad_sch, mini_pcb.kicad_pcb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]
2026-03-03 almost done with mini pcb
    [Input.kicad_sch, Output.kicad_sch, mini_pcb.kicad_pcb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]
2026-03-05 made final touches and bom still needs through testing
    [Input.kicad_sch, Output.kicad_sch, mini_pcb.csv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]
2026-04-24 ordered pcb
    [Input.kicad_sch, Output.kicad_sch, bom.csv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]
2026-05-17 made mini-pcb report
    [Input.kicad_sch, mini_pcb.kicad_pcb, mini_pcb.kicad_sch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]
2026-05-29 I will be re writing the code to use the daisy-embassy library because the Daisy one i have been using has a strange but crush effect when there is just a normal passthrough but the daisy-embassy exa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
    [Input.kicad_sch, mini_pcb.kicad_pcb, mini_pcb.kicad_sch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]
2026-05-30 cleaned up
    [esp32-fx_v2.kicad_pcb, esp32-fx_v2.kicad_sch, sym.kicad_pcb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]
2026-06-17 started working on new wifi pcb
    [Input.kicad_sch, Output.kicad_sch, bom.csv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]
2026-06-26 trouble with defmt
    [Input.kicad_sch, Output.kicad_sch, full_pcb.kicad_pcb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]
2026-07-02 got the fft to work YAY!
    [Input.kicad_sch, Output.kicad_sch, full_pcb.kicad_pcb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]
2026-07-12 working esp32 HTTP server
2026-07-12 esp32 websocket example working
2026-07-13 tried to get SPI working
    SPI drivers are thin on the esp-hal side and the ESP32 would not be able to initiate communication because of the master/slave setup, so I will try to get UART working.
    [full_pcb.kicad_pcb, full_pcb.kicad_sch]
2026-07-15 got UART to work
2026-07-15 got pcb ready
    [full_pcb.kicad_pcb]
2026-07-29 finished FFT sisplay test waiting for new PCB to arrive
    [bom.csv, designators.csv, full_pcb.kicad_pcb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]
2026-08-19 pedal works but is buggy
    [Input.kicad_sch, Output.kicad_sch, bom.csv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]
2026-08-19 tried to optimize the esp32 code
2026-08-20 added uart dma. untested
2026-08-25 did ~16% optimization of websocket on esp32
2026-08-26 made const changes, untested, need to implment diffrent types going on uart
2026-08-29 added pcobs and f32, i16, and i8 uart and websocket transfers *untested*
2026-08-29 website not loading problems
    [main.rs]
2026-08-31 webpage works but uart is broken
    [main.rs]
2026-09-20 Update projects and ignore build output
    [Input.kicad_sch, Output.kicad_sch, full_pcb.kicad_pcb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]
2026-10-05 updated pictures
    [power.kicad_sch, seed-pedal.kicad_pcb]
